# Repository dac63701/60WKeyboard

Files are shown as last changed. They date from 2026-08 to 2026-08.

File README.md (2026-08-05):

# Custom Keyboard Project
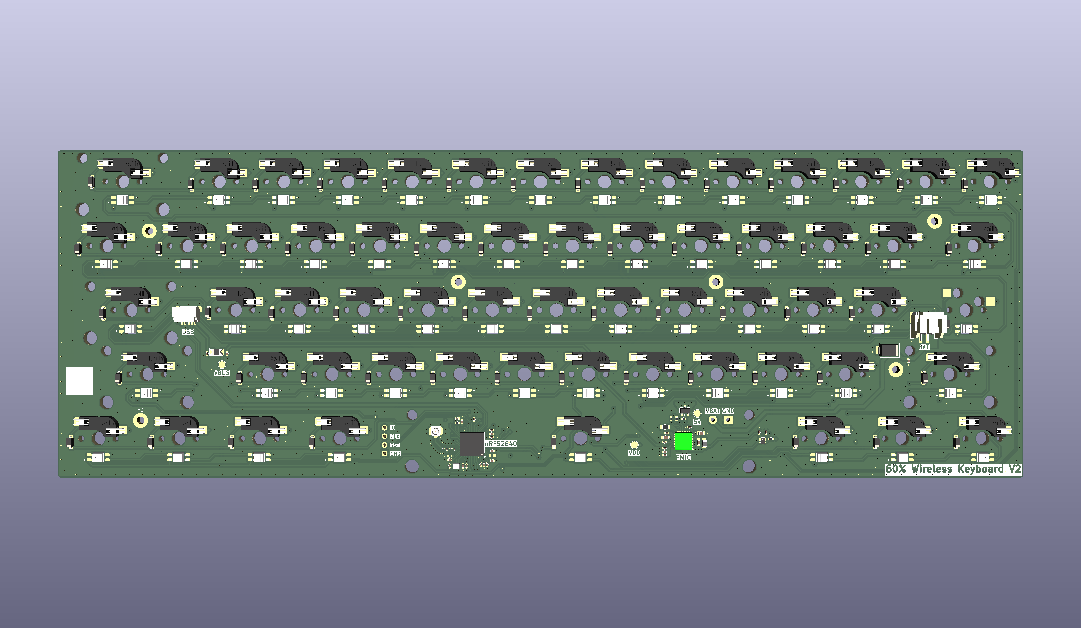
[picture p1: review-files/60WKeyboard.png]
Screenshot of the keyboard in 3d.

A wireless, 60% layout, hot swappable, custom keyboard designed with an nRF52840 in Kicad. This keyboard is meant to be as efficient as possible for longer battery life.

## Criteria
- Wireless
- 60% Layout
- RGB Lighting
- Good Battery Life
- Cherry MX Switch Form Factor
- Hotswap Switches

## Materials
- [ ] PCBs ([JLCPCB](https://jlcpcb.com))
- [ ] Solder Stencil ([JLCPCB](https://jlcpcb.com))
- [x] Solder Paste ([Amazon](https://www.amazon.com/gp/product/B0BLSJQPR6/ref=ox_sc_act_title_7?smid=A1NSYQXYRWRLYY&psc=1))
- [x] Flux ([Amazon](https://www.amazon.com/gp/product/B08KJRCYRH/ref=ox_sc_act_title_8?smid=A2GPLZGUK8NBW5&psc=1))
- [x] Lead-Free Solder ([Amazon](https://www.amazon.com/gp/product/B07Q167J98/ref=ewc_pr_img_4?smid=A2SCLCWYE2XLX3&psc=1))
- [x] Solder Wick ([Amazon](https://www.amazon.com/gp/product/B094GZ6CPZ/ref=ox_sc_act_title_11?smid=ATC1HM24MD6HA&psc=1))
- [x] Solder Tip Tinner ([Amazon](https://www.amazon.com/gp/product/B00NS4J6BY/ref=ewc_pr_img_1?smid=A614WYM65K035&psc=1))
- [x] Switches ([Gateron Milky Yellows](https://www.amazon.com/gp/product/B0BBPD1W9W/ref=ox_sc_act_title_13?smid=A3L9NMSYTD5SO9&psc=1))
- [x] Hot Swap Sockets ([Amazon](https://www.amazon.com/gp/product/B0B4W9YMGM/ref=ox_sc_act_title_14?smid=A1G6HFHDKP9H5J&psc=1))
- [ ] Stabilizers ([Amazon](https://www.amazon.com/gp/product/B0CN36LV22/ref=ox_sc_act_title_12?smid=A1G6HFHDKP9H5J&psc=1))
- [x] Keycaps (Aliexpress)
- [ ] Case (3d Printed)

## Electronic Components ([Digikey](https://www.digikey.com/))
- Main MCU - [nRF52840](https://www.nordicsemi.com/Products/nRF52840)
- PMIC - [nPM1300](https://www.nordicsemi.com/Products/nPM1300)
- RGB LEDs - [SK6812mini-e](https://www.aliexpress.us/item/3256809003632879.html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)
- Supporting Components...

## Tools
- [x] Adjustable Temperature Soldering Iron ([8786D](https://www.amazon.com/gp/product/B0BXN5NXFQ/ref=ox_sc_act_title_6?smid=A1YPRZ9PDHRQA5&psc=1))
- [x] Hot Air Station ([8786D](https://www.amazon.com/gp/product/B0BXN5NXFQ/ref=ox_sc_act_title_6?smid=A1YPRZ9PDHRQA5&psc=1))
- [x] Hot Plate (Amazon)
- [x] Fume Extractor ([Kotto](https://www.amazon.com/gp/product/B07VWDN29F/ref=ox_sc_act_title_2?smid=A38V7SOCF2OM8H&psc=1))
- [x] Digital Microscope ([AD246S-M](https://www.amazon.com/gp/product/B09VPPS96M/ref=ox_sc_act_title_5?smid=A2YDP7W2SGBPL2&psc=1))
- [x] Tweezers (Amazon)
- [x] Helping Hands ([Amazon](https://www.amazon.com/gp/product/B0BHHVP467/ref=ox_sc_act_title_10?smid=A3FKADQL4BXVZ2&psc=1))
- [x] Soldering Iron Brass Sponge ([Amazon](https://www.amazon.com/gp/product/B08FQBS97L/ref=ox_sc_act_title_9?smid=ATVPDKIKX0DER&psc=1))
- [x] 3d Printer

## Steps
1. [x] Select Components
2. [x] Design Schematic
3. [x] Design PCB
4. [ ] Order PCB and Stencil
5. [ ] Order Electronic Components
6. [x] Acquire the necessary tools
7. [ ] Assemble boards
8. [ ] Test and validate

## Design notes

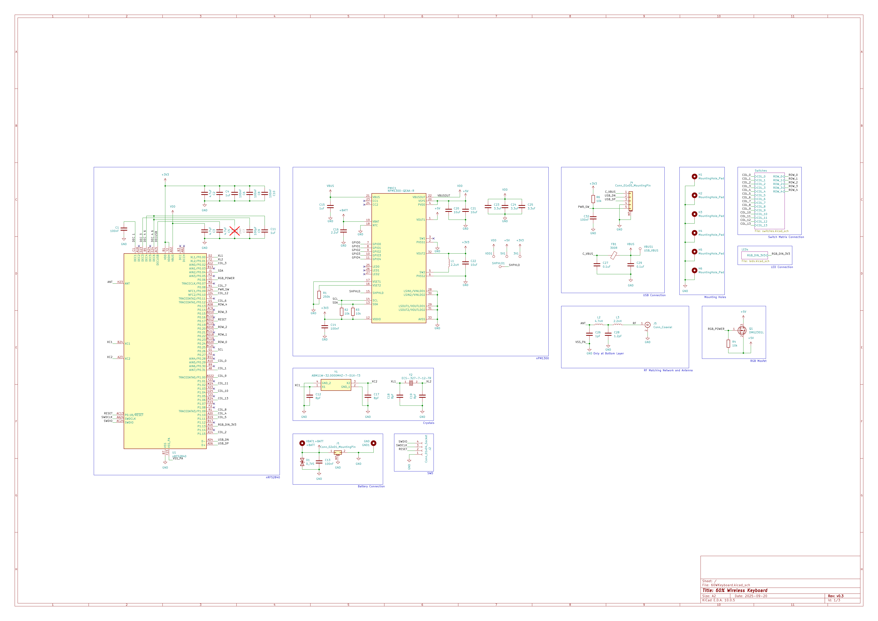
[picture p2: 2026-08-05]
review-files/schematics/60WKeyboard.png

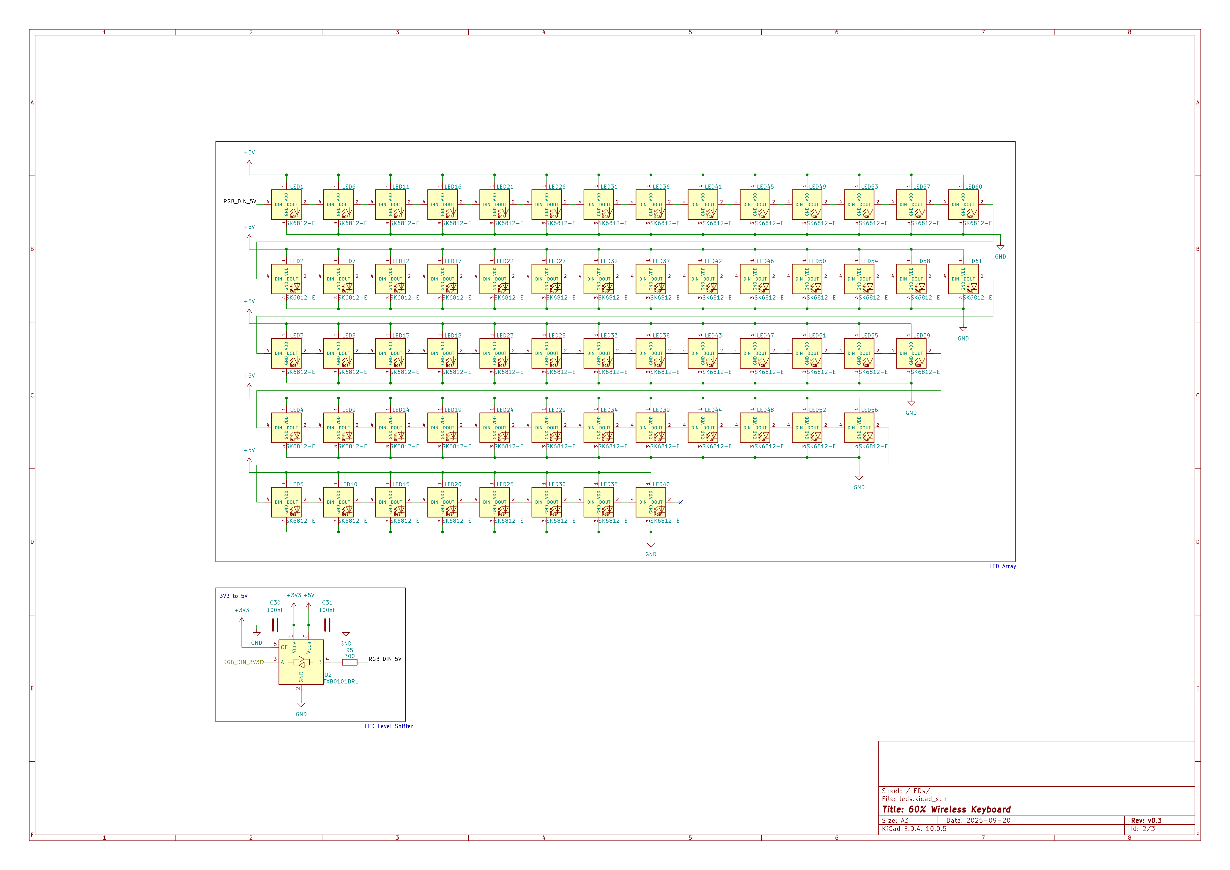
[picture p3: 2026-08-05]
review-files/schematics/60WKeyboard-LEDs.png

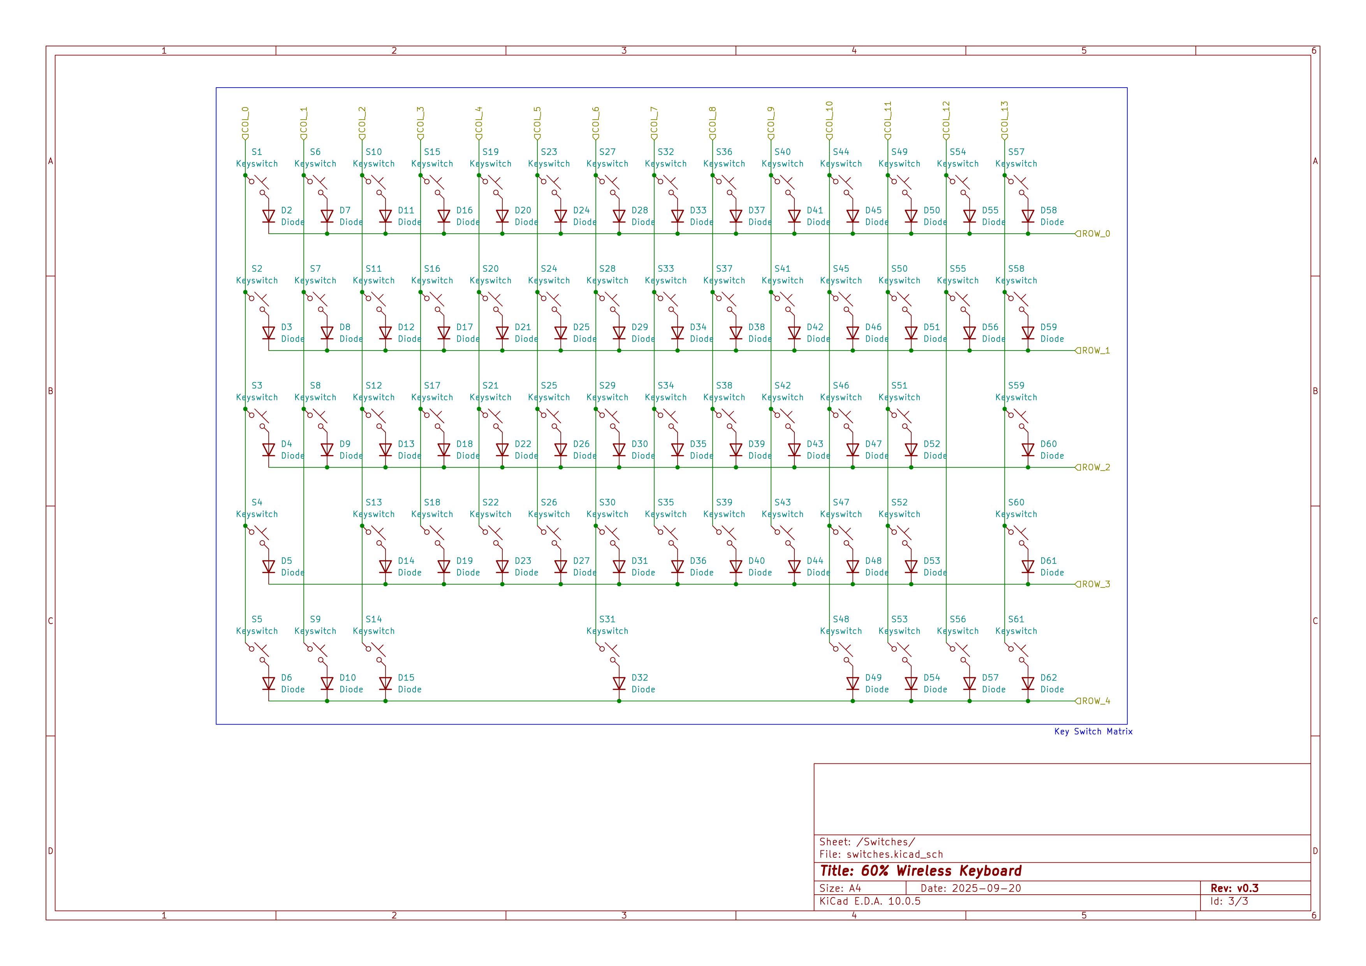
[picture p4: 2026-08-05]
review-files/schematics/60WKeyboard-Switches.png

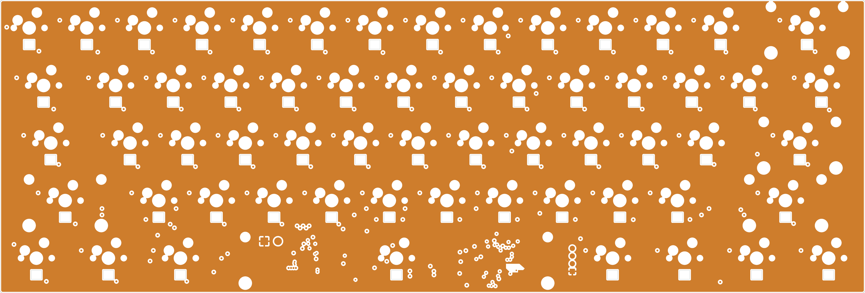
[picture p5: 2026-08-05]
review-files/layers/60WKeyboard-In2_Cu.png

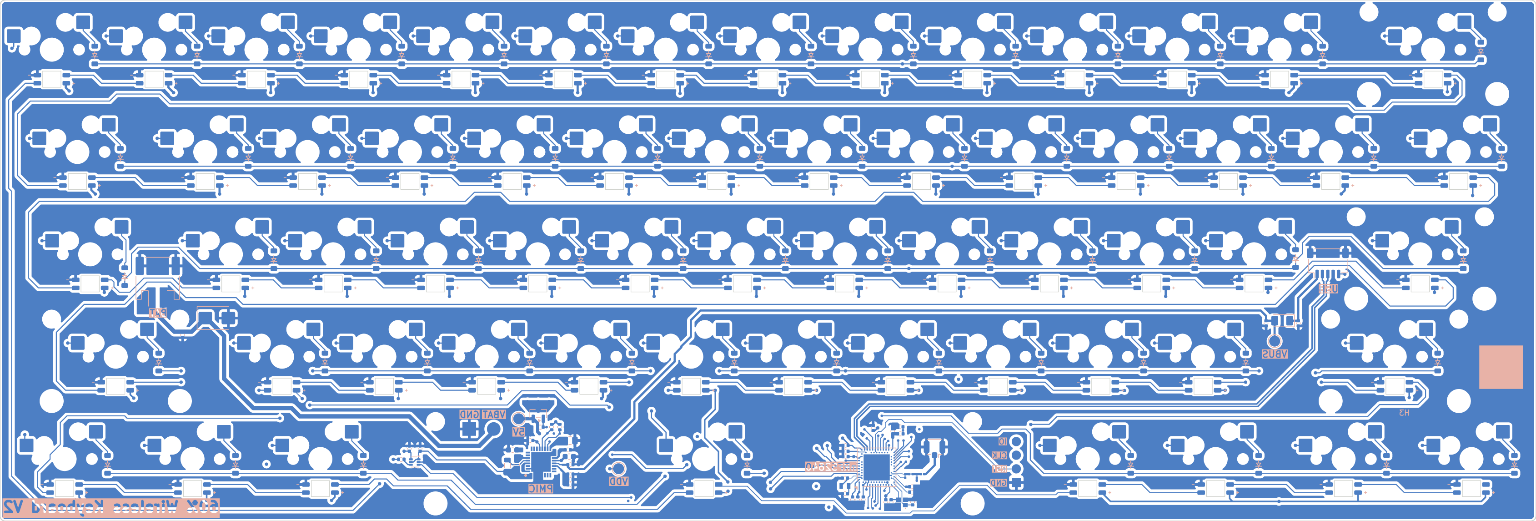
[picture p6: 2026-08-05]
review-files/layers/60WKeyboard-B_Cu.png

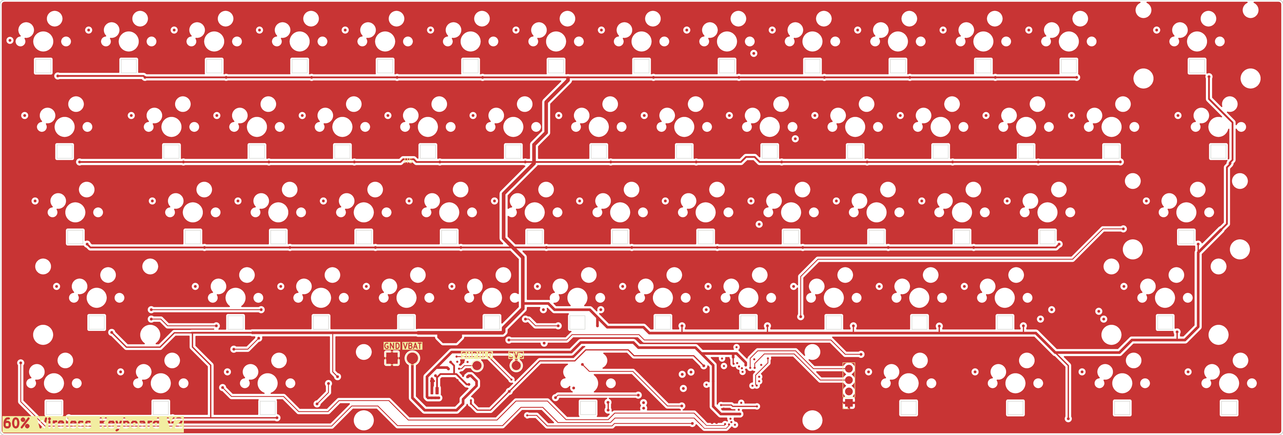
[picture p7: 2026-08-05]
review-files/layers/60WKeyboard-F_Cu.png

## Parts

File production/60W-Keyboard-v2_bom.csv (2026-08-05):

Designator | Footprint | Quantity | Value | LCSC Part #
3V3, VBUS | TestPoint_Pad_D2.0mm | 2 | USB_VBUS
5V | TestPoint_Pad_D2.0mm | 1 | 5V
C1, C10, C13, C14, C30, C31, C32, C33, C34, C35, C36, C37, C38, C39, C40, C41, C42, C43, C44, C45, C46, C47, C48, C49, C50, C51, C52, C53, C54, C55, C56, C57, C58, C59, C6, C60, C61, C62, C63, C64, C65, C66, C67, C68, C69, C70, C71, C72, C73, C74, C75, C76, C77, C78, C79, C8, C80, C81, C82, C83, C84, C85, C86, C87, C88, C89, C90, C91, C92, C93 | 0402 | 70 | 100nF
C11, C15, C4 | 0402 | 3 | 1uF
C12, C17, C18, C19 | 0402 | 4 | 8pF
C16 | 0402 | 1 | 2.2uF
C2, C3, C5 | 0402 | 3 | 4.7uF
C20, C21, C22 | 0603 | 3 | 10uF
C23, C24, C25 | 0402 | 3 | 3.3uF
C26 | 0201 | 1 | 1pF
C27, C29 | 0402 | 2 | 0.1uF
C28 | 0201 | 1 | 1.2pF
C9 | 0402 | 1 | 100pF
D1 | D_SMB | 1 | D_TVS
D10, D11, D12, D13, D14, D15, D16, D17, D18, D19, D2, D20, D21, D22, D23, D24, D25, D26, D27, D28, D29, D3, D30, D31, D32, D33, D34, D35, D36, D37, D38, D39, D4, D40, D41, D42, D43, D44, D45, D46, D47, D48, D49, D5, D50, D51, D52, D53, D54, D55, D56, D57, D58, D59, D6, D60, D61, D62, D7, D8, D9 | Diode_SOD-123 | 61 | Diode
FB1 | 1206 | 1 | 300R
J1 | JST_PH_S2B-PH-SM4-TB_1x02-1MP_P2.00mm_Horizontal | 1 | Conn_02x01_MountingPin
J2 | PinSocket_1x04_P2.54mm_Vertical | 1 | Conn_01x04_Socket
J4 | JST_SH_SM05B-SRSS-TB_1x05-1MP_P1.00mm_Horizontal | 1 | Conn_01x05_MountingPin
J5 | U.FL_Hirose_U.FL-R-SMT-1_Vertical | 1 | Conn_Coaxial
L1 | 0805 | 1 | 2.2uH
L2 | 0201 | 1 | 4.7nH
L3 | 0201 | 1 | 2.2nH
LED1, LED10, LED11, LED12, LED13, LED14, LED15, LED16, LED17, LED18, LED19, LED2, LED20, LED21, LED22, LED23, LED24, LED25, LED26, LED27, LED28, LED29, LED3, LED30, LED31, LED32, LED33, LED34, LED35, LED36, LED37, LED38, LED39, LED4, LED40, LED41, LED42, LED43, LED44, LED45, LED46, LED47, LED48, LED49, LED5, LED50, LED51, LED52, LED53, LED54, LED55, LED56, LED57, LED58, LED59, LED6, LED60, LED61, LED7, LED8, LED9 | LED_SK6812-E | 61 | SK6812-E
PMIC | QFN50P500X500X90-33N | 1 | NPM1300-QEAA-R
Q1 | SOT-23 | 1 | DMG2301L
R1 | 0805 | 1 | 250k
R2, R3, R4, R6 | 0402 | 4 | 10k
R5 | 0402 | 1 | 300
S1, S10, S11, S12, S13, S15, S16, S17, S18, S19, S20, S21, S22, S23, S24, S25, S26, S27, S28, S29, S30, S32, S33, S34, S35, S36, S37, S38, S39, S40, S41, S42, S43, S44, S45, S46, S47, S49, S50, S51, S52, S54, S55, S6, S7, S8 | MX-Hotswap-1U | 46 | Keyswitch
S14, S48, S5, S53, S56, S61, S9 | MX-Hotswap-1.25U | 7 | Keyswitch
S2, S58 | MX-Hotswap-1.5U | 2 | Keyswitch
S3 | MX-Hotswap-1.75U | 1 | Keyswitch
S31 | MX-Hotswap-6.25U-ReversedStabilizers | 1 | Keyswitch
S4, S59 | MX-Hotswap-2.25U | 2 | Keyswitch
S57 | MX-Hotswap-2U | 1 | Keyswitch
S60 | MX-Hotswap-2.75U | 1 | Keyswitch
SHPHLD, VDD | TestPoint_Pad_D2.0mm | 2 | VBUSOUT
U1 | Nordic_AQFN-73-1EP_7x7mm_P0.5mm | 1 | nRF52840
U2 | SOT-563 | 1 | TXB0101DRL
Y1 | ABM11W300000MHZ4B1UT3 | 1 | ABM11W-32.0000MHZ-7-D1X-T3
Y2 | XTAL_ECS-.327-7-12-TR | 1 | ECS-.327-7-12-TR

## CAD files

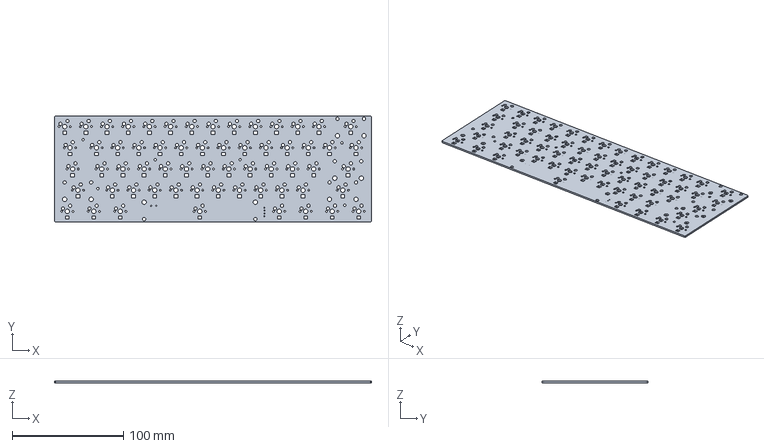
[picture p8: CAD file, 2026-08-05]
production/60WKeyboard.step
285.0 x 95.0 x 1.52 mm

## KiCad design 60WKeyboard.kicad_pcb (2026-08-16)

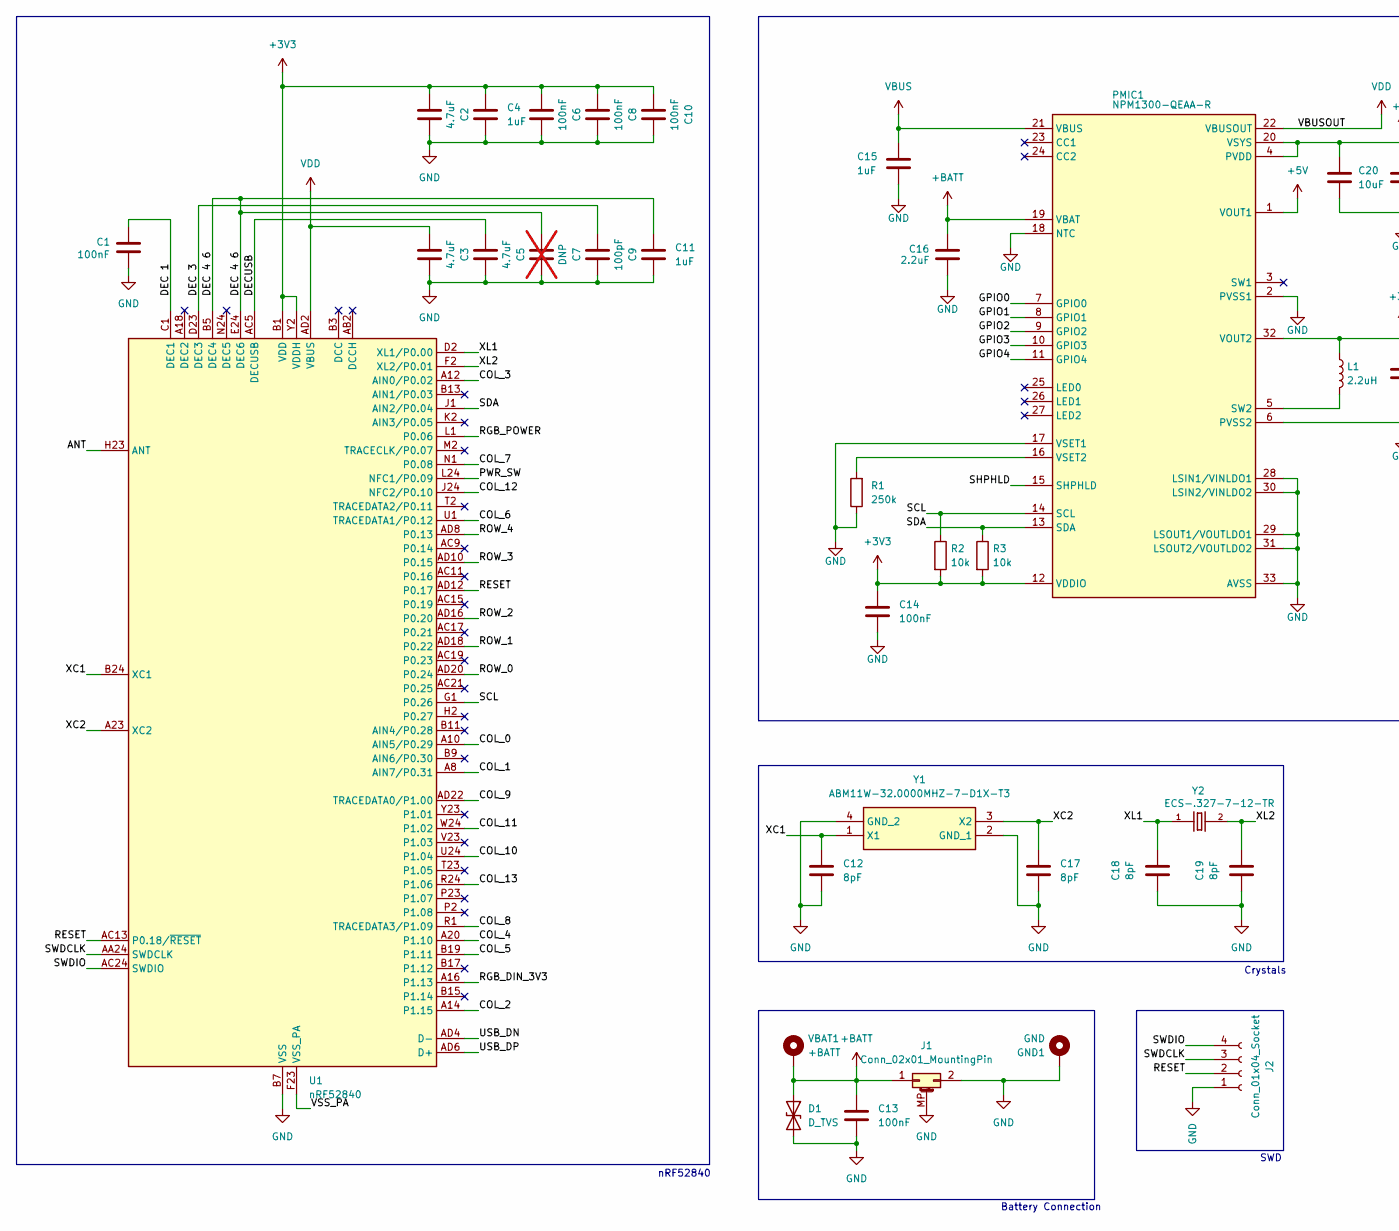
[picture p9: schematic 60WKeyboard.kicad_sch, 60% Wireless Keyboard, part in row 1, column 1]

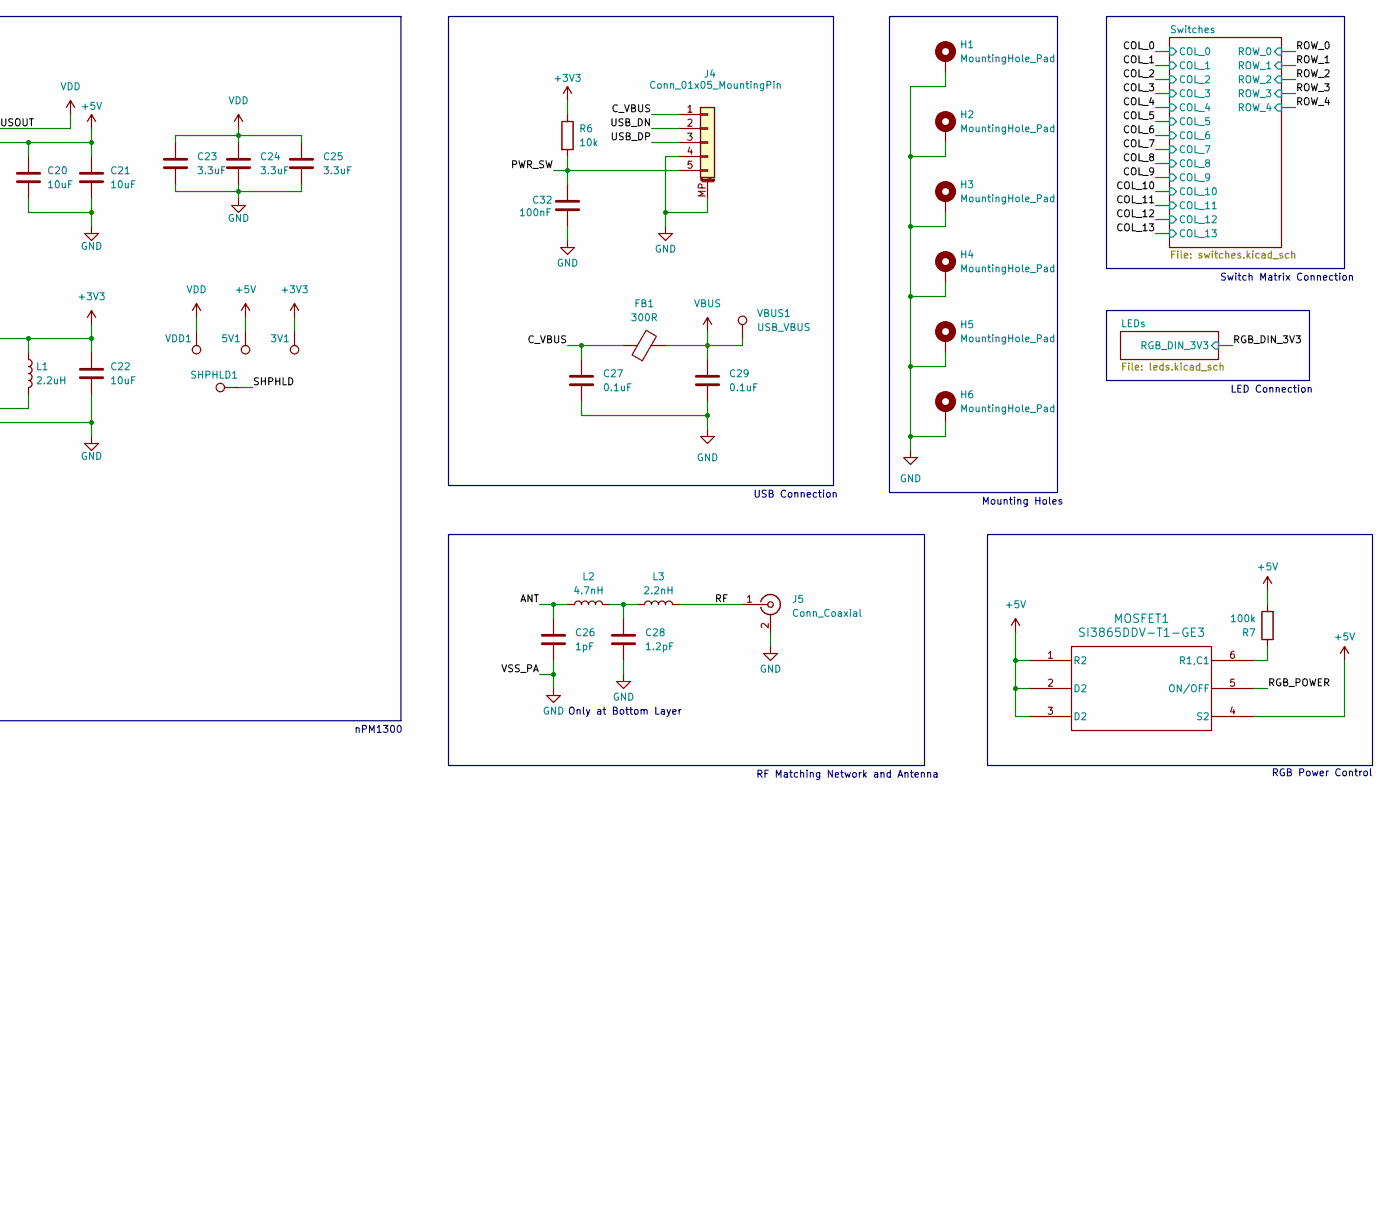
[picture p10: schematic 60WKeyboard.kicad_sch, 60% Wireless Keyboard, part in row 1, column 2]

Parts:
3V1: USB_VBUS; TestPoint_Pad_D2.0mm
5V1: 5V; TestPoint_Pad_D2.0mm
C1, C6, C8, C10, C13, C14, C32: 100nF; C_0402_1005Metric
C2, C3, C5: 4.7uF; C_0402_1005Metric
C4, C11, C15: 1uF; C_0402_1005Metric
C7: DNP; C_0402_1005Metric; not fitted
C9: 100pF; C_0402_1005Metric
C12, C17, C18, C19: 8pF; C_0402_1005Metric
C16: 2.2uF; C_0402_1005Metric
C20, C21, C22: 10uF; C_0603_1608Metric
C23, C24, C25: 3.3uF; C_0402_1005Metric
C26: 1pF; C_0201_0603Metric
C27, C29: 0.1uF; C_0402_1005Metric
C28: 1.2pF; C_0201_0603Metric
D1: D_TVS; D_SMB
FB1: 300R; D_1206_3216Metric
GND1: GND; TestPoint_THTPad_2.5x2.5mm_Drill1.2mm
H1, H2, H3, H4, H5, H6: MountingHole_Pad; MountingHole_2.2mm_M2_Pad
J1: Conn_02x01_MountingPin; JST_PH_S2B-PH-SM4-TB_1x02-1MP_P2.00mm_Horizontal
J2: Conn_01x04_Socket; PinSocket_1x04_P2.54mm_Vertical
J4: Conn_01x05_MountingPin; JST_SH_SM05B-SRSS-TB_1x05-1MP_P1.00mm_Horizontal
J5: Conn_Coaxial; U.FL_Hirose_U.FL-R-SMT-1_Vertical
L1: 2.2uH; L_0805_2012Metric
L2: 4.7nH; L_0201_0603Metric
L3: 2.2nH; L_0201_0603Metric
MOSFET1: SI3865DDV-T1-GE3; TSOP6_MO-193C_VIS
PMIC1: NPM1300-QEAA-R; QFN50P500X500X90-33N; Mouser Part Number 949-NPM1300-QEAA-R7
R1: 250k; R_0805_2012Metric
R2, R3, R6: 10k; R_0402_1005Metric
R7: 100k; R_0402_1005Metric
SHPHLD1: VBUSOUT; TestPoint_Pad_D2.0mm
U1: nRF52840; Nordic_AQFN-73-1EP_7x7mm_P0.5mm
VBAT1: +BATT; TestPoint_THTPad_D2.5mm_Drill1.2mm
VBUS1: USB_VBUS; TestPoint_Pad_D2.0mm
VDD1: VBUSOUT; TestPoint_Pad_D2.0mm
Y1: ABM11W-32.0000MHZ-7-D1X-T3; ABM11W300000MHZ4B1UT3; Mouser Part Number 815-11W32-7D1XT
Y2: ECS-.327-7-12-TR; XTAL_ECS-.327-7-12-TR; PARTREV 2017

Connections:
+3V3: 3V1.1, C2.1, C4.2, C6.1, C8.1, C10.1, C14.1, C22.1, L1.1, PMIC1.12 (VDDIO), PMIC1.32 (VOUT2), R2.2, R3.2, R6.1, U1.A22 (VDD), U1.AD14 (VDD), U1.AD23 (VDD), U1.B1 (VDD), U1.W1 (VDD), U1.Y2 (VDDH); also elsewhere on the board
+5V: 5V1.1, C20.1, C21.1, MOSFET1.1 (R2), MOSFET1.2 (D2), MOSFET1.3 (D2), MOSFET1.4 (S2), PMIC1.1 (VOUT1), PMIC1.4 (PVDD), PMIC1.20 (VSYS), R7.2; also elsewhere on the board
+BATT: C13.1, C16.2, D1.1 (A1), J1.1, PMIC1.19 (VBAT), VBAT1.1; also elsewhere on the board
/ANT: C26.1, L2.1, U1.H23 (ANT)
/COL_0: U1.A10 (AIN5/P0.29); also elsewhere on the board
/COL_1: U1.A8 (AIN7/P0.31); also elsewhere on the board
/COL_2: U1.A14 (P1.15); also elsewhere on the board
/COL_3: U1.A12 (AIN0/P0.02); also elsewhere on the board
/COL_4: U1.A20 (P1.10); also elsewhere on the board
/COL_5: U1.B19 (P1.11); also elsewhere on the board
/COL_6: U1.U1 (TRACEDATA1/P0.12); also elsewhere on the board
/COL_7: U1.N1 (P0.08); also elsewhere on the board
/COL_8: U1.R1 (TRACEDATA3/P1.09); also elsewhere on the board
/COL_9: U1.AD22 (TRACEDATA0/P1.00); also elsewhere on the board
/COL_10: U1.U24 (P1.04); also elsewhere on the board
/COL_11: U1.W24 (P1.02); also elsewhere on the board
/COL_12: U1.J24 (NFC2/P0.10); also elsewhere on the board
/COL_13: U1.R24 (P1.06); also elsewhere on the board
/C_VBUS: C27.1, FB1.1, J4.1
/DEC 1: C1.2, U1.C1 (DEC1)
/DEC 3: C9.1, U1.D23 (DEC3)
/DEC 4 6: C7.1, C11.2, U1.B5 (DEC4), U1.E24 (DEC6)
/DECUSB: C5.1, U1.AC5 (DECUSB)
/PWR_SW: C32.2, J4.5, R6.2, U1.L24 (NFC1/P0.09)
/RESET: J2.2, U1.AC13 (P0.18/~RESET), U1.AD12 (P0.17)
/RF: J5.1 (In), L3.2
/RGB_DIN_3V3: U1.A16 (P1.13); also elsewhere on the board
/RGB_POWER: MOSFET1.5 (ON/OFF), U1.L1 (P0.06)
/ROW_0: U1.AD20 (P0.24); also elsewhere on the board
/ROW_1: U1.AD18 (P0.22); also elsewhere on the board
/ROW_2: U1.AD16 (P0.20); also elsewhere on the board
/ROW_3: U1.AD10 (P0.15); also elsewhere on the board
/ROW_4: U1.AD8 (P0.13); also elsewhere on the board
/SCL: PMIC1.14 (SCL), R2.1, U1.G1 (P0.26); also elsewhere on the board
/SDA: PMIC1.13 (SDA), R3.1, U1.J1 (AIN2/P0.04); also elsewhere on the board
/SWDCLK: J2.3, U1.AA24 (SWDCLK)
/SWDIO: J2.4, U1.AC24 (SWDIO)
/USB_DN: J4.2, U1.AD4 (D-)
/USB_DP: J4.3, U1.AD6 (D+)
/XC1: C12.1, U1.B24 (XC1), Y1.1 (X1)
/XC2: C17.1, U1.A23 (XC2), Y1.3 (X2)
/XL1: C18.2, U1.D2 (XL1/P0.00), Y2.1
/XL2: C19.2, U1.F2 (XL2/P0.01), Y2.2
GND: C1.1, C2.2, C3.2, C4.1, C5.2, C6.2, C7.2, C8.2, C9.2, C10.2, C11.1, C12.2, C13.2, C14.2, C15.2, C16.1, C17.2, C18.1, C19.1, C20.2, C21.2, C22.2, C23.2, C24.2, C25.2, C26.2, C27.2, C28.2, C29.2, C32.1, D1.2 (A2), GND1.1, H1.1 (1_1), H2.1 (1_1), H3.1 (1_1), H4.1 (1_1), H5.1 (1_1), H6.1 (1_1), J1.2, J1.MP (MountPin), J2.1, J4.4, J4.MP (MountPin), J5.2 (Ext), PMIC1.2 (PVSS1), PMIC1.6 (PVSS2), PMIC1.17 (VSET1), PMIC1.18 (NTC), PMIC1.28 (LSIN1/VINLDO1), PMIC1.29 (LSOUT1/VOUTLDO1), PMIC1.30 (LSIN2/VINLDO2), PMIC1.31 (LSOUT2/VOUTLDO2), PMIC1.33 (AVSS), R1.1, U1.B7 (VSS), U1.EP (VSS), U1.F23 (VSS_PA), Y1.2 (GND_1), Y1.4 (GND_2); also elsewhere on the board
unnamed: C28.1, L2.2, L3.1
unnamed: MOSFET1.6 (R1,C1), R7.1
unnamed: PMIC1.15 (SHPHLD), SHPHLD1.1
unnamed 175: L1.2, PMIC1.5 (SW2); also elsewhere on the board
unnamed 176: PMIC1.16 (VSET2), R1.2; also elsewhere on the board
VBUS: C15.1, C29.1, FB1.2, PMIC1.21 (VBUS), VBUS1.1; also elsewhere on the board
VDD: C3.1, C23.1, C24.1, C25.1, PMIC1.22 (VBUSOUT), U1.AD2 (VBUS), VDD1.1; also elsewhere on the board

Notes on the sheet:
Battery Connection
LED Connection
nRF52840
Crystals
Switch Matrix Connection
SWD
USB Connection
Only at Bottom Layer
nPM1300
Mounting Holes
RGB Power Control
RF Matching Network and Antenna

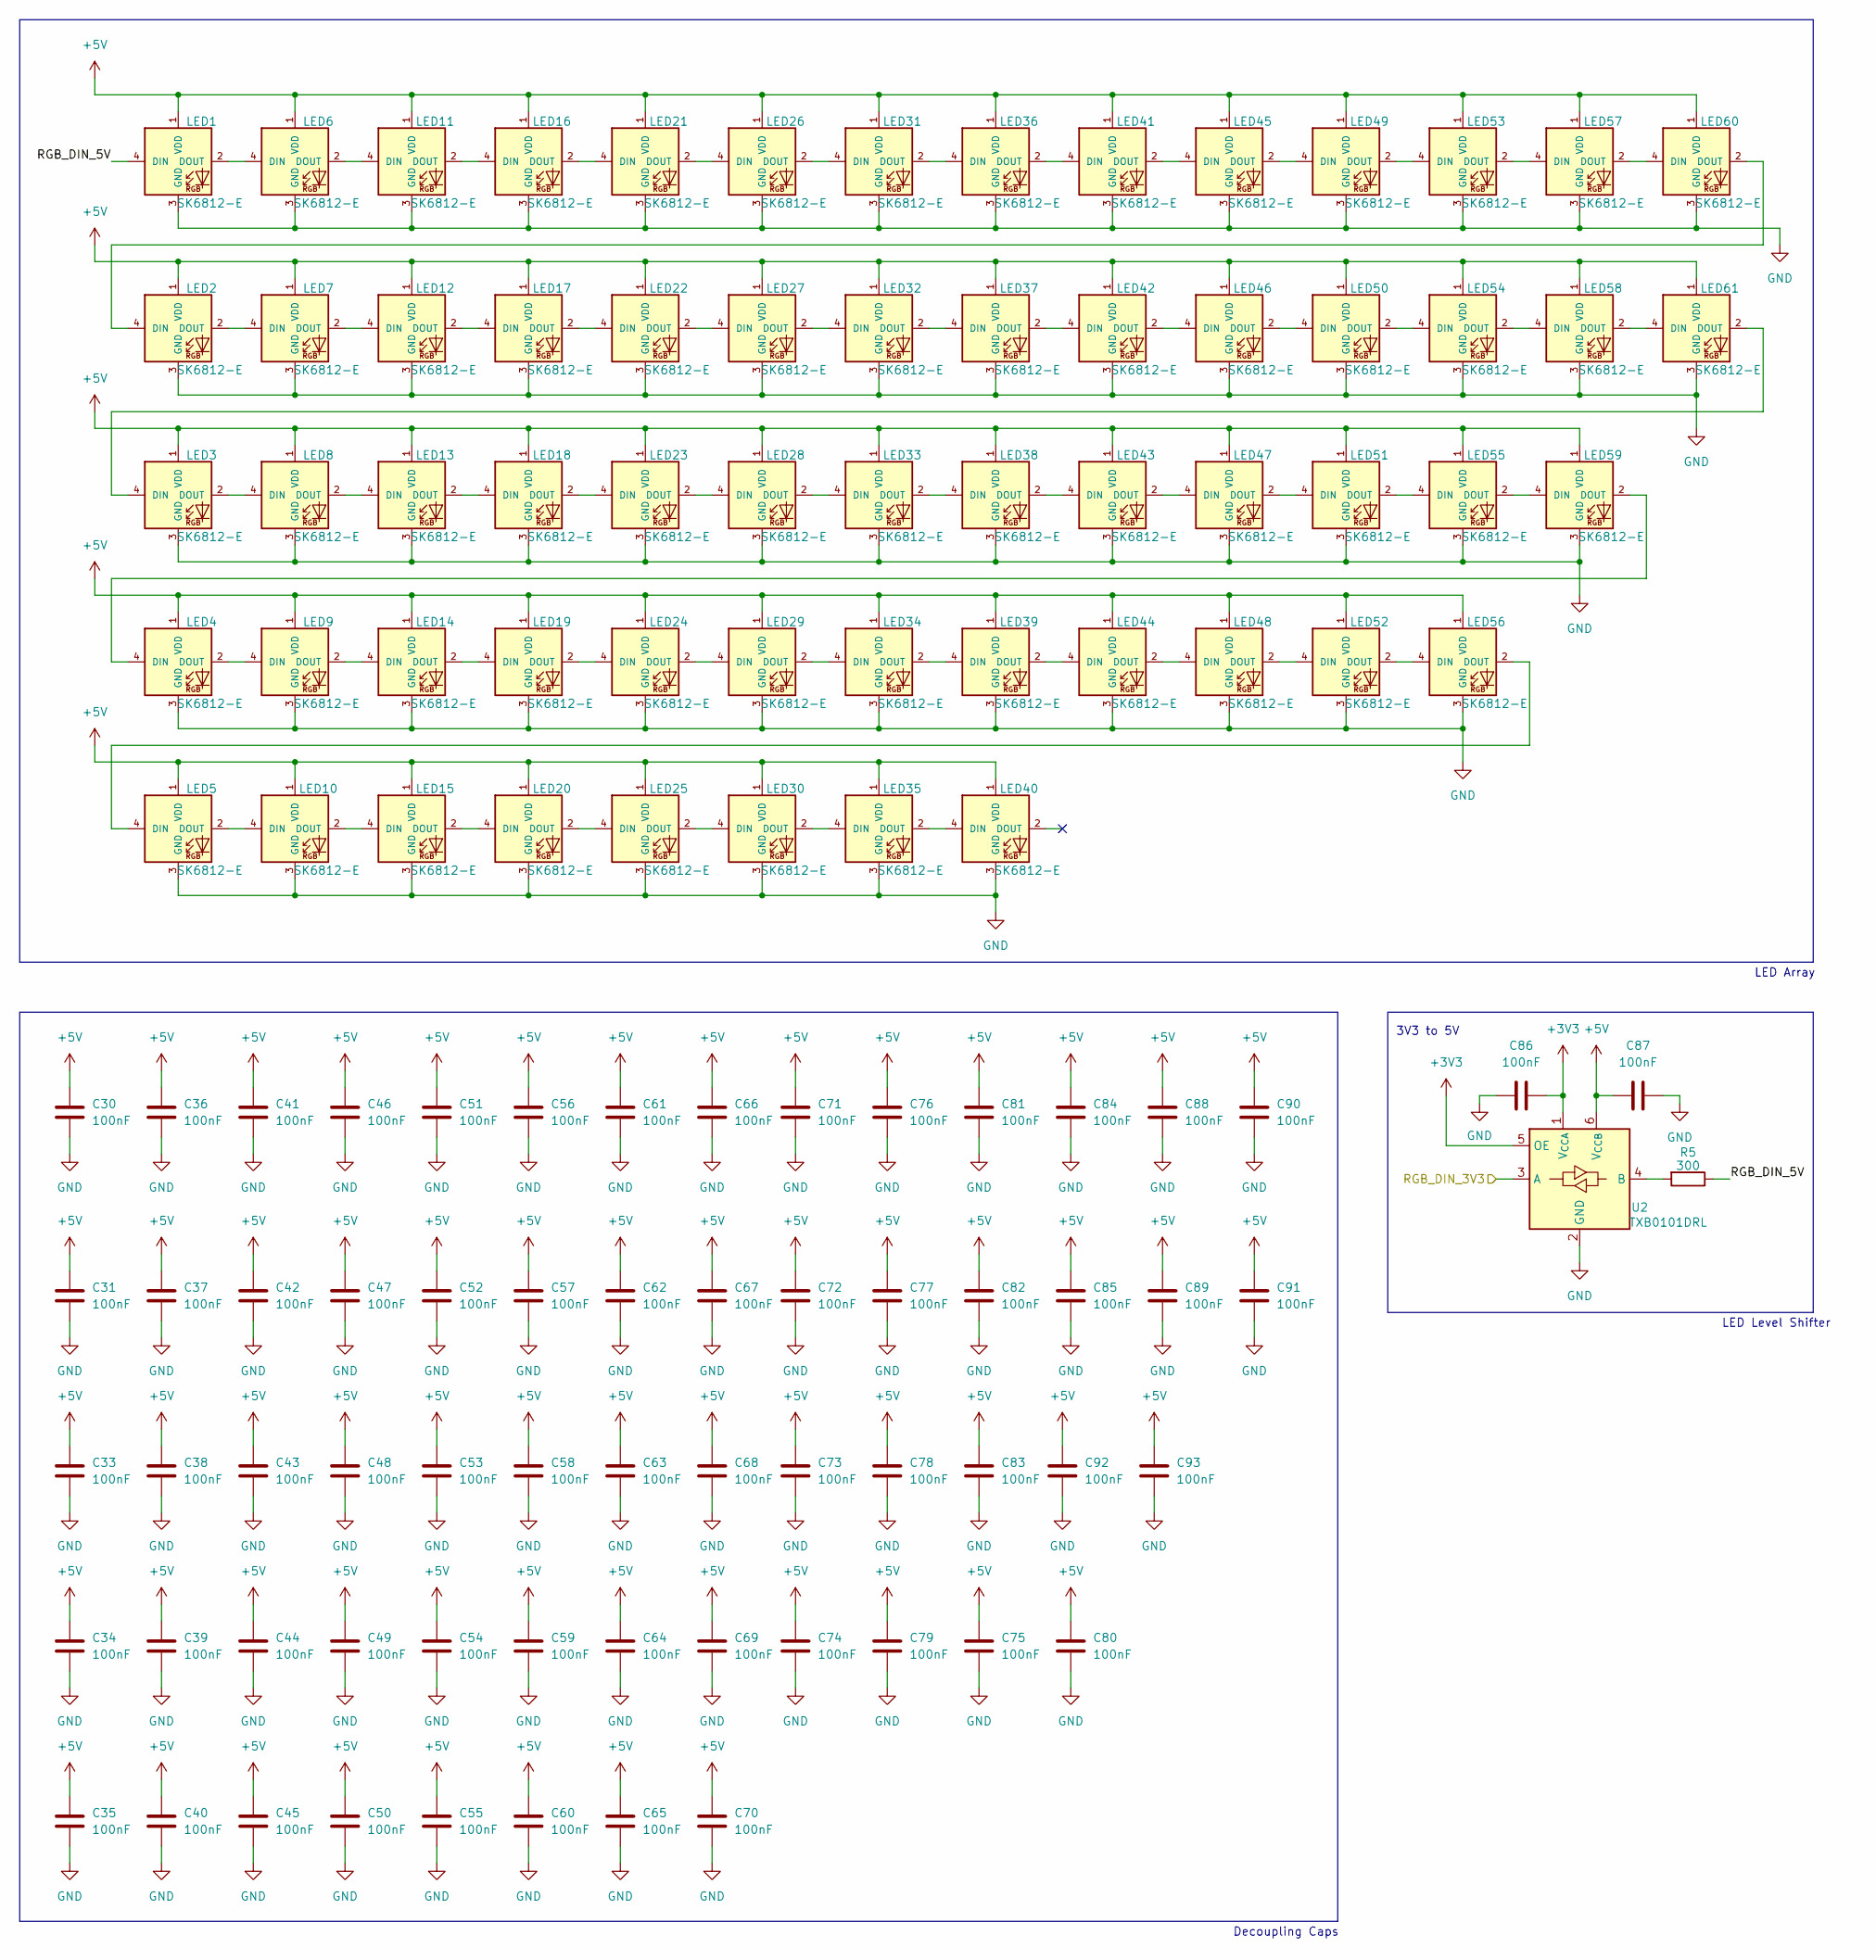
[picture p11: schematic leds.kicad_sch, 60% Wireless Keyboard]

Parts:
C30, C31, C33, C34, C35, C36, C37, C38, C39, C40, C41, C42, C43, C44, C45, C46, C47, C48, C49, C50, C51, C52, C53, C54, C55, C56, C57, C58, C59, C60, C61, C62, C63, C64, C65, C66, C67, C68, C69, C70, C71, C72, C73, C74, C75, C76, C77, C78, C79, C80, C81, C82, C83, C84, C85, C86, C87, C88, C89, C90, C91, C92, C93: 100nF; C_0402_1005Metric
LED1, LED2, LED3, LED4, LED5, LED6, LED7, LED8, LED9, LED10, LED11, LED12, LED13, LED14, LED15, LED16, LED17, LED18, LED19, LED20, LED21, LED22, LED23, LED24, LED25, LED26, LED27, LED28, LED29, LED30, LED31, LED32, LED33, LED34, LED35, LED36, LED37, LED38, LED39, LED40, LED41, LED42, LED43, LED44, LED45, LED46, LED47, LED48, LED49, LED50, LED51, LED52, LED53, LED54, LED55, LED56, LED57, LED58, LED59, LED60, LED61: SK6812-E; LED_SK6812-E; PARTREV 2
R5: 300; R_0402_1005Metric
U2: TXB0101DRL; SOT-563

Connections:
+3V3: C86.2, U2.1 (V_{CCA}), U2.5 (OE); also elsewhere on the board
+5V: C30.1, C31.1, C33.1, C34.1, C35.1, C36.1, C37.1, C38.1, C39.1, C40.1, C41.1, C42.1, C43.1, C44.1, C45.1, C46.1, C47.1, C48.1, C49.1, C50.1, C51.1, C52.1, C53.1, C54.1, C55.1, C56.1, C57.1, C58.1, C59.1, C60.1, C61.1, C62.1, C63.1, C64.1, C65.1, C66.1, C67.1, C68.1, C69.1, C70.1, C71.1, C72.1, C73.1, C74.1, C75.1, C76.1, C77.1, C78.1, C79.1, C80.1, C81.1, C82.1, C83.1, C84.1, C85.1, C87.1, C88.1, C89.1, C90.1, C91.1, C92.1, C93.1, LED1.1 (VDD), LED2.1 (VDD), LED3.1 (VDD), LED4.1 (VDD), LED5.1 (VDD), LED6.1 (VDD), LED7.1 (VDD), LED8.1 (VDD), LED9.1 (VDD), LED10.1 (VDD), LED11.1 (VDD), LED12.1 (VDD), LED13.1 (VDD), LED14.1 (VDD), LED15.1 (VDD), LED16.1 (VDD), LED17.1 (VDD), LED18.1 (VDD), LED19.1 (VDD), LED20.1 (VDD), LED21.1 (VDD), LED22.1 (VDD), LED23.1 (VDD), LED24.1 (VDD), LED25.1 (VDD), LED26.1 (VDD), LED27.1 (VDD), LED28.1 (VDD), LED29.1 (VDD), LED30.1 (VDD), LED31.1 (VDD), LED32.1 (VDD), LED33.1 (VDD), LED34.1 (VDD), LED35.1 (VDD), LED36.1 (VDD), LED37.1 (VDD), LED38.1 (VDD), LED39.1 (VDD), LED40.1 (VDD), LED41.1 (VDD), LED42.1 (VDD), LED43.1 (VDD), LED44.1 (VDD), LED45.1 (VDD), LED46.1 (VDD), LED47.1 (VDD), LED48.1 (VDD), LED49.1 (VDD), LED50.1 (VDD), LED51.1 (VDD), LED52.1 (VDD), LED53.1 (VDD), LED54.1 (VDD), LED55.1 (VDD), LED56.1 (VDD), LED57.1 (VDD), LED58.1 (VDD), LED59.1 (VDD), LED60.1 (VDD), LED61.1 (VDD), U2.6 (V_{CCB}); also elsewhere on the board
/LEDs/RGB_DIN_5V: LED1.4 (DIN), R5.1
/RGB_DIN_3V3: U2.3 (A); also elsewhere on the board
GND: C30.2, C31.2, C33.2, C34.2, C35.2, C36.2, C37.2, C38.2, C39.2, C40.2, C41.2, C42.2, C43.2, C44.2, C45.2, C46.2, C47.2, C48.2, C49.2, C50.2, C51.2, C52.2, C53.2, C54.2, C55.2, C56.2, C57.2, C58.2, C59.2, C60.2, C61.2, C62.2, C63.2, C64.2, C65.2, C66.2, C67.2, C68.2, C69.2, C70.2, C71.2, C72.2, C73.2, C74.2, C75.2, C76.2, C77.2, C78.2, C79.2, C80.2, C81.2, C82.2, C83.2, C84.2, C85.2, C86.1, C87.2, C88.2, C89.2, C90.2, C91.2, C92.2, C93.2, LED1.3 (GND), LED2.3 (GND), LED3.3 (GND), LED4.3 (GND), LED5.3 (GND), LED6.3 (GND), LED7.3 (GND), LED8.3 (GND), LED9.3 (GND), LED10.3 (GND), LED11.3 (GND), LED12.3 (GND), LED13.3 (GND), LED14.3 (GND), LED15.3 (GND), LED16.3 (GND), LED17.3 (GND), LED18.3 (GND), LED19.3 (GND), LED20.3 (GND), LED21.3 (GND), LED22.3 (GND), LED23.3 (GND), LED24.3 (GND), LED25.3 (GND), LED26.3 (GND), LED27.3 (GND), LED28.3 (GND), LED29.3 (GND), LED30.3 (GND), LED31.3 (GND), LED32.3 (GND), LED33.3 (GND), LED34.3 (GND), LED35.3 (GND), LED36.3 (GND), LED37.3 (GND), LED38.3 (GND), LED39.3 (GND), LED40.3 (GND), LED41.3 (GND), LED42.3 (GND), LED43.3 (GND), LED44.3 (GND), LED45.3 (GND), LED46.3 (GND), LED47.3 (GND), LED48.3 (GND), LED49.3 (GND), LED50.3 (GND), LED51.3 (GND), LED52.3 (GND), LED53.3 (GND), LED54.3 (GND), LED55.3 (GND), LED56.3 (GND), LED57.3 (GND), LED58.3 (GND), LED59.3 (GND), LED60.3 (GND), LED61.3 (GND), U2.2 (GND); also elsewhere on the board
unnamed: LED1.2 (DOUT), LED6.4 (DIN)
unnamed: LED2.4 (DIN), LED60.2 (DOUT)
unnamed: LED2.2 (DOUT), LED7.4 (DIN)
unnamed: LED3.4 (DIN), LED61.2 (DOUT)
unnamed: LED3.2 (DOUT), LED8.4 (DIN)
unnamed: LED4.4 (DIN), LED59.2 (DOUT)
unnamed: LED4.2 (DOUT), LED9.4 (DIN)
unnamed: LED5.4 (DIN), LED56.2 (DOUT)
unnamed: LED5.2 (DOUT), LED10.4 (DIN)
unnamed: LED10.2 (DOUT), LED15.4 (DIN)
unnamed: LED6.2 (DOUT), LED11.4 (DIN)
unnamed: LED11.2 (DOUT), LED16.4 (DIN)
unnamed: LED7.2 (DOUT), LED12.4 (DIN)
unnamed: LED12.2 (DOUT), LED17.4 (DIN)
unnamed: LED8.2 (DOUT), LED13.4 (DIN)
unnamed: LED13.2 (DOUT), LED18.4 (DIN)
unnamed: LED9.2 (DOUT), LED14.4 (DIN)
unnamed: LED14.2 (DOUT), LED19.4 (DIN)
unnamed: LED15.2 (DOUT), LED20.4 (DIN)
unnamed: LED16.2 (DOUT), LED21.4 (DIN)
unnamed: LED17.2 (DOUT), LED22.4 (DIN)
unnamed: LED18.2 (DOUT), LED23.4 (DIN)
unnamed: LED19.2 (DOUT), LED24.4 (DIN)
unnamed: LED20.2 (DOUT), LED25.4 (DIN)
unnamed: LED21.2 (DOUT), LED26.4 (DIN)
unnamed: LED22.2 (DOUT), LED27.4 (DIN)
unnamed: LED23.2 (DOUT), LED28.4 (DIN)
unnamed: LED24.2 (DOUT), LED29.4 (DIN)
unnamed: LED25.2 (DOUT), LED30.4 (DIN)
unnamed: LED26.2 (DOUT), LED31.4 (DIN)
unnamed: LED27.2 (DOUT), LED32.4 (DIN)
unnamed: LED28.2 (DOUT), LED33.4 (DIN)
unnamed: LED29.2 (DOUT), LED34.4 (DIN)
unnamed: LED30.2 (DOUT), LED35.4 (DIN)
unnamed: LED31.2 (DOUT), LED36.4 (DIN)
unnamed: LED32.2 (DOUT), LED37.4 (DIN)
unnamed: LED33.2 (DOUT), LED38.4 (DIN)
unnamed: LED34.2 (DOUT), LED39.4 (DIN)
unnamed: LED35.2 (DOUT), LED40.4 (DIN)
unnamed: LED36.2 (DOUT), LED41.4 (DIN)
unnamed: LED37.2 (DOUT), LED42.4 (DIN)
unnamed: LED38.2 (DOUT), LED43.4 (DIN)
unnamed: LED39.2 (DOUT), LED44.4 (DIN)
unnamed: LED41.2 (DOUT), LED45.4 (DIN)
unnamed: LED42.2 (DOUT), LED46.4 (DIN)
unnamed: LED43.2 (DOUT), LED47.4 (DIN)
unnamed: LED44.2 (DOUT), LED48.4 (DIN)
unnamed: LED45.2 (DOUT), LED49.4 (DIN)
unnamed: LED46.2 (DOUT), LED50.4 (DIN)
unnamed: LED47.2 (DOUT), LED51.4 (DIN)
unnamed: LED48.2 (DOUT), LED52.4 (DIN)
unnamed: LED49.2 (DOUT), LED53.4 (DIN)
unnamed: LED50.2 (DOUT), LED54.4 (DIN)
unnamed: LED51.2 (DOUT), LED55.4 (DIN)
unnamed: LED52.2 (DOUT), LED56.4 (DIN)
unnamed: LED53.2 (DOUT), LED57.4 (DIN)
unnamed: LED54.2 (DOUT), LED58.4 (DIN)
unnamed: LED55.2 (DOUT), LED59.4 (DIN)
unnamed: LED57.2 (DOUT), LED60.4 (DIN)
unnamed: LED58.2 (DOUT), LED61.4 (DIN)
unnamed: R5.2, U2.4 (B)

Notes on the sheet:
3V3 to 5V
LED Array
LED Level Shifter
Decoupling Caps

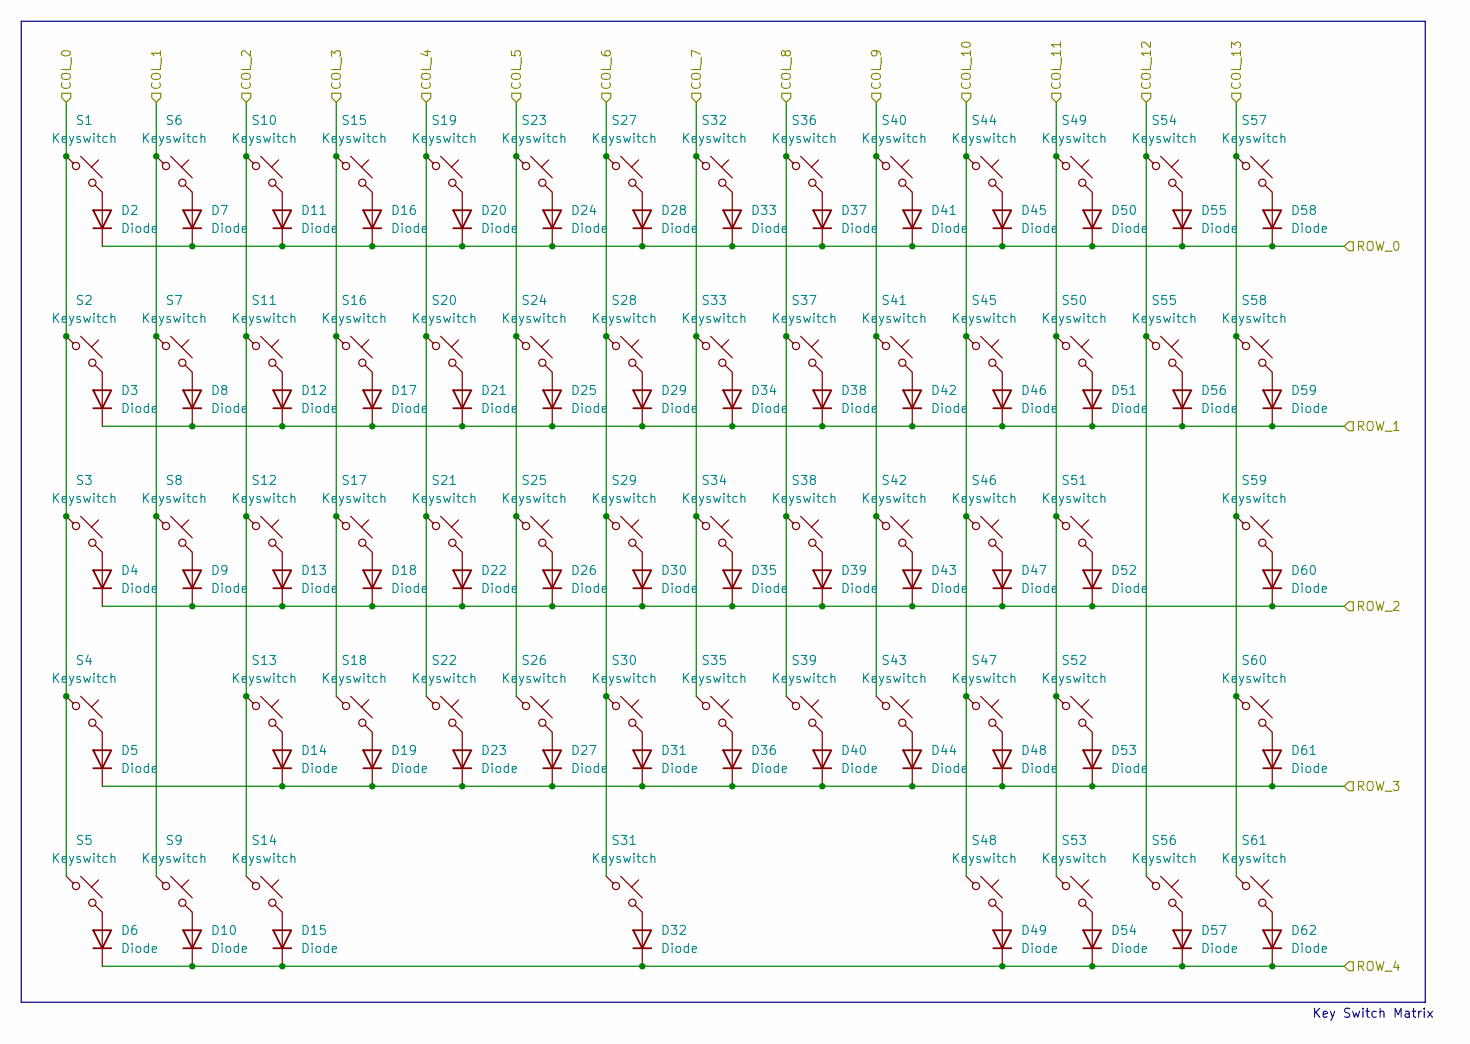
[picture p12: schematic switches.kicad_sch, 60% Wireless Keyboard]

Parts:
D2, D3, D4, D5, D6, D7, D8, D9, D10, D11, D12, D13, D14, D15, D16, D17, D18, D19, D20, D21, D22, D23, D24, D25, D26, D27, D28, D29, D30, D31, D32, D33, D34, D35, D36, D37, D38, D39, D40, D41, D42, D43, D44, D45, D46, D47, D48, D49, D50, D51, D52, D53, D54, D55, D56, D57, D58, D59, D60, D61, D62: Diode; Diode_SOD-123
S1, S6, S7, S8, S10, S11, S12, S13, S15, S16, S17, S18, S19, S20, S21, S22, S23, S24, S25, S26, S27, S28, S29, S30, S32, S33, S34, S35, S36, S37, S38, S39, S40, S41, S42, S43, S44, S45, S46, S47, S49, S50, S51, S52, S54, S55: Keyswitch; MX-Hotswap-1U
S2, S58: Keyswitch; MX-Hotswap-1.5U
S3: Keyswitch; MX-Hotswap-1.75U
S4, S59: Keyswitch; MX-Hotswap-2.25U
S5, S9, S14, S48, S53, S56, S61: Keyswitch; MX-Hotswap-1.25U
S31: Keyswitch; MX-Hotswap-6.25U-ReversedStabilizers
S57: Keyswitch; MX-Hotswap-2U
S60: Keyswitch; MX-Hotswap-2.75U

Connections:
/COL_0: S1.1, S2.1, S3.1, S4.1, S5.1; also elsewhere on the board
/COL_1: S6.1, S7.1, S8.1, S9.1; also elsewhere on the board
/COL_2: S10.1, S11.1, S12.1, S13.1, S14.1; also elsewhere on the board
/COL_3: S15.1, S16.1, S17.1, S18.1; also elsewhere on the board
/COL_4: S19.1, S20.1, S21.1, S22.1; also elsewhere on the board
/COL_5: S23.1, S24.1, S25.1, S26.1; also elsewhere on the board
/COL_6: S27.1, S28.1, S29.1, S30.1, S31.1; also elsewhere on the board
/COL_7: S32.1, S33.1, S34.1, S35.1; also elsewhere on the board
/COL_8: S36.1, S37.1, S38.1, S39.1; also elsewhere on the board
/COL_9: S40.1, S41.1, S42.1, S43.1; also elsewhere on the board
/COL_10: S44.1, S45.1, S46.1, S47.1, S48.1; also elsewhere on the board
/COL_11: S49.1, S50.1, S51.1, S52.1, S53.1; also elsewhere on the board
/COL_12: S54.1, S55.1, S56.1; also elsewhere on the board
/COL_13: S57.1, S58.1, S59.1, S60.1, S61.1; also elsewhere on the board
/ROW_0: D2.1 (K), D7.1 (K), D11.1 (K), D16.1 (K), D20.1 (K), D24.1 (K), D28.1 (K), D33.1 (K), D37.1 (K), D41.1 (K), D45.1 (K), D50.1 (K), D55.1 (K), D58.1 (K); also elsewhere on the board
/ROW_1: D3.1 (K), D8.1 (K), D12.1 (K), D17.1 (K), D21.1 (K), D25.1 (K), D29.1 (K), D34.1 (K), D38.1 (K), D42.1 (K), D46.1 (K), D51.1 (K), D56.1 (K), D59.1 (K); also elsewhere on the board
/ROW_2: D4.1 (K), D9.1 (K), D13.1 (K), D18.1 (K), D22.1 (K), D26.1 (K), D30.1 (K), D35.1 (K), D39.1 (K), D43.1 (K), D47.1 (K), D52.1 (K), D60.1 (K); also elsewhere on the board
/ROW_3: D5.1 (K), D14.1 (K), D19.1 (K), D23.1 (K), D27.1 (K), D31.1 (K), D36.1 (K), D40.1 (K), D44.1 (K), D48.1 (K), D53.1 (K), D61.1 (K); also elsewhere on the board
/ROW_4: D6.1 (K), D10.1 (K), D15.1 (K), D32.1 (K), D49.1 (K), D54.1 (K), D57.1 (K), D62.1 (K); also elsewhere on the board
unnamed: D2.2 (A), S1.2
unnamed: D3.2 (A), S2.2
unnamed: D4.2 (A), S3.2
unnamed: D5.2 (A), S4.2
unnamed: D6.2 (A), S5.2
unnamed: D7.2 (A), S6.2
unnamed: D8.2 (A), S7.2
unnamed: D9.2 (A), S8.2
unnamed: D10.2 (A), S9.2
unnamed: D11.2 (A), S10.2
unnamed: D12.2 (A), S11.2
unnamed: D13.2 (A), S12.2
unnamed: D14.2 (A), S13.2
unnamed: D15.2 (A), S14.2
unnamed: D16.2 (A), S15.2
unnamed: D17.2 (A), S16.2
unnamed: D18.2 (A), S17.2
unnamed: D19.2 (A), S18.2
unnamed: D20.2 (A), S19.2
unnamed: D21.2 (A), S20.2
unnamed: D22.2 (A), S21.2
unnamed: D23.2 (A), S22.2
unnamed: D24.2 (A), S23.2
unnamed: D25.2 (A), S24.2
unnamed: D26.2 (A), S25.2
unnamed: D27.2 (A), S26.2
unnamed: D28.2 (A), S27.2
unnamed: D29.2 (A), S28.2
unnamed: D30.2 (A), S29.2
unnamed: D31.2 (A), S30.2
unnamed: D32.2 (A), S31.2
unnamed: D33.2 (A), S32.2
unnamed: D34.2 (A), S33.2
unnamed: D35.2 (A), S34.2
unnamed: D36.2 (A), S35.2
unnamed: D37.2 (A), S36.2
unnamed: D38.2 (A), S37.2
unnamed: D39.2 (A), S38.2
unnamed: D40.2 (A), S39.2
unnamed: D41.2 (A), S40.2
unnamed: D42.2 (A), S41.2
unnamed: D43.2 (A), S42.2
unnamed: D44.2 (A), S43.2
unnamed: D45.2 (A), S44.2
unnamed: D46.2 (A), S45.2
unnamed: D47.2 (A), S46.2
unnamed: D48.2 (A), S47.2
unnamed: D49.2 (A), S48.2
unnamed: D50.2 (A), S49.2
unnamed: D51.2 (A), S50.2
unnamed: D52.2 (A), S51.2
unnamed: D53.2 (A), S52.2
unnamed: D54.2 (A), S53.2
unnamed: D55.2 (A), S54.2
unnamed: D56.2 (A), S55.2
unnamed: D57.2 (A), S56.2
unnamed: D58.2 (A), S57.2
unnamed: D59.2 (A), S58.2
unnamed: D60.2 (A), S59.2
unnamed: D61.2 (A), S60.2
unnamed: D62.2 (A), S61.2

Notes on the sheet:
Key Switch Matrix

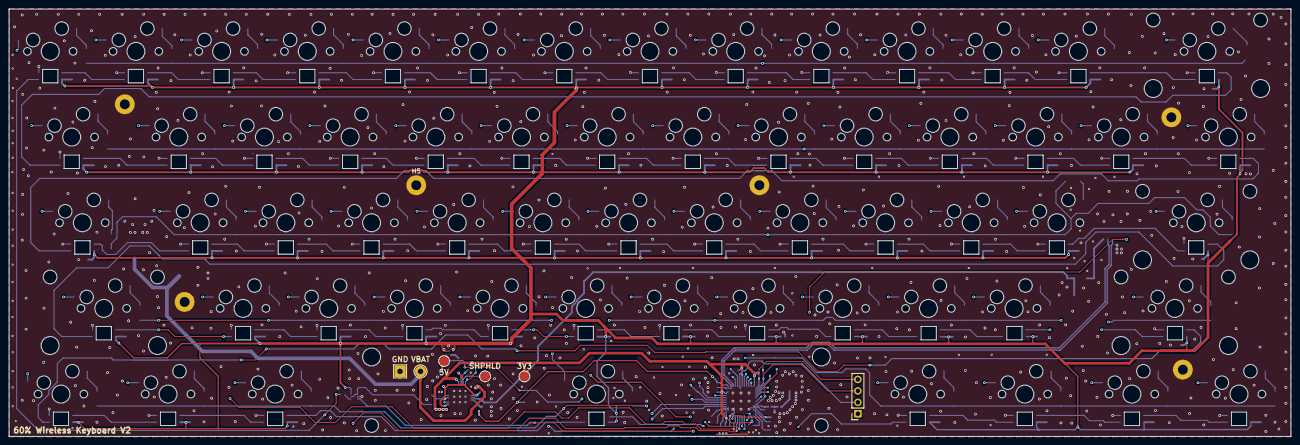
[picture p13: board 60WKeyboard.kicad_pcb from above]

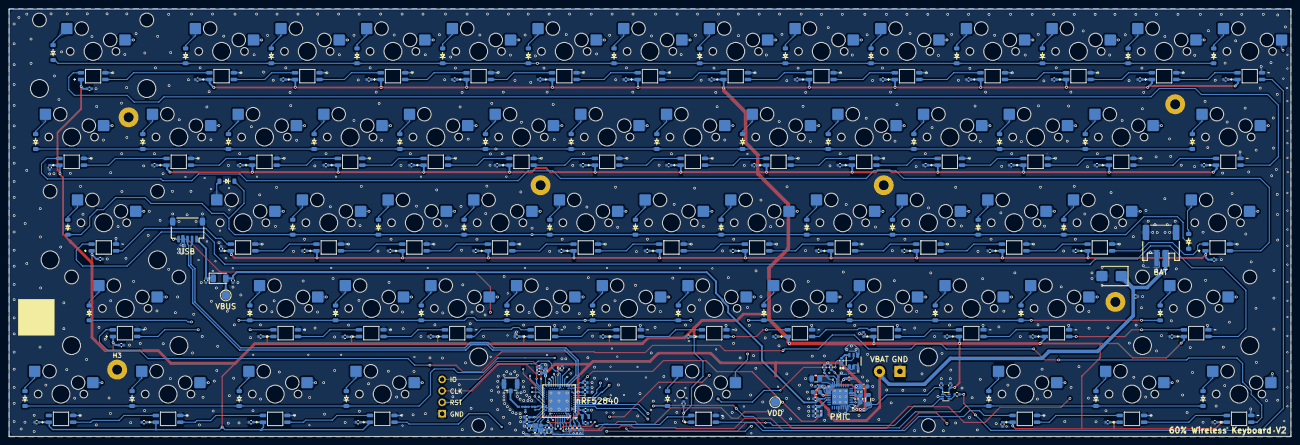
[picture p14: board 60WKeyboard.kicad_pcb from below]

Board: 4 copper layers, 285.0 x 95.0 mm, 310 parts (299 on the bottom side), 174 nets.

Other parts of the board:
3V3: USB_VBUS; TestPoint_Pad_D2.0mm
5V: 5V; TestPoint_Pad_D2.0mm
GND: GND; TestPoint_THTPad_2.5x2.5mm_Drill1.2mm
PMIC: NPM1300-QEAA-R; QFN50P500X500X90-33N
SHPHLD: VBUSOUT; TestPoint_Pad_D2.0mm
VBAT: +BATT; TestPoint_THTPad_D2.5mm_Drill1.2mm
VBUS: USB_VBUS; TestPoint_Pad_D2.0mm
VDD: VBUSOUT; TestPoint_Pad_D2.0mm

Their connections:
+3V3: 3V3.1 (1_1), PMIC.12 (VDDIO), PMIC.32 (VOUT2); also elsewhere on the board
+5V: 5V.1 (1_1), PMIC.1 (VOUT1), PMIC.4 (PVDD), PMIC.20 (VSYS); also elsewhere on the board
+BATT: PMIC.19 (VBAT), VBAT.1 (1_1); also elsewhere on the board
/SCL: PMIC.14 (SCL); also elsewhere on the board
/SDA: PMIC.13 (SDA); also elsewhere on the board
/SHPHLD: PMIC.15 (SHPHLD), SHPHLD.1 (1_1)
GND: GND.1 (1_1), PMIC.2 (PVSS1), PMIC.6 (PVSS2), PMIC.17 (VSET1), PMIC.18 (NTC), PMIC.28 (LSIN1/VINLDO1), PMIC.29 (LSOUT1/VOUTLDO1), PMIC.30 (LSIN2/VINLDO2), PMIC.31 (LSOUT2/VOUTLDO2), PMIC.33 (AVSS); also elsewhere on the board
unnamed 175: PMIC.5 (SW2); also elsewhere on the board
unnamed 176: PMIC.16 (VSET2); also elsewhere on the board
VBUS: PMIC.21 (VBUS), VBUS.1 (1_1); also elsewhere on the board
VDD: PMIC.22 (VBUSOUT), VDD.1 (1_1); also elsewhere on the board

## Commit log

2025-07-03 v0.1-sch
    finished schematic
    [60WKeyboard.kicad_sch]
2025-07-06 work towards v0.2
    Complete rework of design from nrf52840 module to nrf54l15 SOC with custom design. Adding new PMIC - npm1300 and supporting components for better fit on board and power savings.
    [60WKeyboard.kicad_sch, leds.kicad_sch, switches.kicad_sch]
2025-07-07 initial v0.2 schematic
    Finished initial schematic. nPM1300 and nRF54l15 are wired up.
    [60WKeyboard.kicad_sch]
2025-07-08 created v0.2 pcb
    Started work on v0.2 pcb. Placed switches, LEDS, and Diodes. Working on MCU routing
    [60WKeyboard.kicad_pcb, 60WKeyboard.kicad_sch, leds.kicad_sch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]
2025-07-10 v0.2 in dev
    MCU change because im stupid and now I have to redo rf. Routed columns. Started routing USB port.
    [60WKeyboard.kicad_pcb, 60WKeyboard.kicad_sch]
2025-07-12 work towards v0.2
    Finished updating schematic. Ported to PCB editor. Need to rethink encoder.
    [60WKeyboard.kicad_pcb, 60WKeyboard.kicad_sch, leds.kicad_sch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]
2025-07-13 work on v0.2
    Moved USB port a bit to facilitate easier routing of the ESD protection. Connected all diodes to keys. Connected most LEDS together.
    [60WKeyboard.kicad_pcb]
2025-07-17 work towards v0.2
    QFAA needs replacement with QIAA
    [60WKeyboard.kicad_pcb]
2025-07-26 more work towards v0.2
    [60WKeyboard.kicad_sch]
2025-09-21 v0.3
    moving along
    everything on board
    need to wire chip and batt charger ic
    switch matrix mostly done
    [60WKeyboard.kicad_pcb, 60WKeyboard.kicad_sch, leds.kicad_sch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]
2025-09-22 v0.3
    mcu power traces done
    moving onto pmic
    then connect key matrix
    then done?
    [60WKeyboard.kicad_sch]
2025-09-23 v0.3
    finished npm1300 routing
    just columns and rows to go
    get review
    order
    [60WKeyboard.kicad_sch]
2025-09-24 v0.3
    done
    waiting for review
    [60WKeyboard.kicad_sch, bom.csv, designators.csv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]
2025-10-12 v0.3
    finally finished
    [60WKeyboard.kicad_sch, bom.csv, designators.csv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]
2025-10-23 Check off completed materials and steps
    Updated the materials and steps sections to reflect completed tasks.
2026-08-05 added bom
    [bom.csv]
2026-08-05 bom.csv location move
    its in the right location now
    [bom.csv]
2026-08-05 Add RGB power control circuit and update PCB
    Introduced a new RGB power control circuit using a DMG2301L MOSFET and 10k resistor, connected to the /RGB_POWER net. Updated test point references, modified net assignments, and adjusted routing and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
    [60WKeyboard.kicad_pcb, 60WKeyboard.kicad_sch, bom.csv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]
2026-08-05 v0.3 complete
    everything fixed (vias are good now) fixed all the other stuff too
    [60WKeyboard.kicad_pcb, positions.csv]
2026-08-05 updated review files
    [60WKeyboard.kicad_pcb]
2026-08-05 Replace RF footprint and add U.FL connector
    Replaced the AMCA31-2R450G-S1F-T3 RF footprint with a CONMHF1-SMD-T U.FL connector at the RF output. Updated the S57 keyswitch footprint position. Also updated backup files and production outputs to reflect these changes.
    [60WKeyboard.kicad_pcb, 60WKeyboard.kicad_sch, bom.csv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]
2026-08-05 Update KiCad project files and backup
    Removed autosave and lock files, updated project and schematic files, and renamed backup ZIP. Changed footprint property for connector in schematic and adjusted selection filter for footprints in pro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
    [60WKeyboard.kicad_sch]
2026-08-05 Update PCB plot parameters and review files
    Modified plot layer selection parameters in 60WKeyboard.kicad_pcb and updated all related review PDFs and backup ZIP to reflect the latest board changes.
    [60WKeyboard.kicad_pcb]
2026-08-05 v0.4-routing done
    need to work on routing and fix it up but preliminary routing done
    [60WKeyboard.kicad_pcb, 60WKeyboard.kicad_sch]
2026-08-05 v0.4 done
    updated everything
    [60WKeyboard.kicad_pcb, bom.csv, designators.csv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]
2026-08-05 v0.4 update
    more updates to pcb
2026-08-05 v0.4 update
    review files updated
    [60WKeyboard.kicad_pcb]
2026-08-05 Remove KiCad lock files
    Deleted temporary lock files for the PCB and schematic to clean up the repository.
2026-08-05 Update PCB and production files for v0.4 release
    Replaced and added backup and production ZIP files for 60W Keyboard v0.4, updated BOM, designators, and positions CSVs, and modified the PCB and netlist files. Also fixed zone connection and region logic in the PCB file and adjusted project options. These changes support the new v0.4 production release and improve file organization.
    [60W-Keyboard-v0.4_bom.csv, 60W-Keyboard-v0.4_designators.csv, 60W-Keyboard-v0.4_positions.csv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]
2026-08-05 idk what this changes but go back if bad
    [60W-Keyboard-v0.4_bom.csv, 60W-Keyboard-v0.4_designators.csv, 60W-Keyboard-v0.4_positions.csv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]
2026-08-05 Finalize V1
    [60WKeyboard.kicad_pcb, 60WKeyboard.kicad_sch, leds.kicad_sch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]
2026-08-05 v2 is coming along
    [60WKeyboard.kicad_pcb, 60WKeyboard.kicad_sch, leds.kicad_sch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]
2026-08-05 more v2 work
    [60WKeyboard.kicad_pcb, 60WKeyboard.kicad_sch]
2026-08-05 v2 - init done, much fixing to go
    [60WKeyboard.kicad_pcb, 60WKeyboard.kicad_sch]
2026-08-05 v2 - doneish
    [60W-Keyboard-v2_bom.csv, 60W-Keyboard-v2_designators.csv, 60W-Keyboard-v2_positions.csv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]
2026-08-05 v2 done for real this time
    [60W-Keyboard-v2_bom.csv, 60W-Keyboard-v2_designators.csv, 60W-Keyboard-v2_positions.csv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]
2026-08-05 clean up
    [60WKeyboard.step]
2026-08-05 v2 teardrops
    [60WKeyboard.kicad_pcb]
2026-08-07 now its done
    [60WKeyboard.kicad_pcb]
2026-08-10 fixed the p channel mosfet not working
    [60WKeyboard.kicad_pcb, 60WKeyboard.kicad_sch]
